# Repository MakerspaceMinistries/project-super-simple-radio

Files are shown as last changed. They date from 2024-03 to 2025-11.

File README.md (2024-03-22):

# Version Name #

`v<version>-<antenna type><audio output><station select><configuration location>`

- version: version number - corresponds with firmware
- antennta type: 
    O) onboard ESP32 antenna
    U) external antenna (following Espressif's convention)
- audio output:
    S) speakers
    L) line out
- station select:
    S) single station (no selector)
    M) multi station
- configuration location
    H) hardcoded
    R) remote

# Overview #

## Connecting to the radio for programming and debugging ##
There are two ways to connect: 

1. USB->Serial, using pads on the PCB
2. On board USB, via micro USB port on the PCB

USB->Serial appears to be the best for troubleshooting and development, as it is more verbose. To save money, this is achieved by connecting an extermal USB->Serial cable to pads on the PCB. This way one set of USB->Serial hardware can be used for multiple devices.

The ESP32 S3's onboard OTG USB does not appear to recieve the ESP32's debug messages, so it's not a solution for troubleshooting and development. However, it does provide a cheap way to make firmware updates more convenient.

### Linux ###

Create a udev rule so that it is not necessary to set permissions with each connection, by creating this file `/etc/udev/rules.d/99-esp32s3.rules` and adding this lines:

```
ATTRS{idVendor}=="303a", ATTRS{idProduct}=="1001", MODE="0666", ENV{ID_MM_DEVICE_IGNORE}="1", ENV{ID_MM_PORT_IGNORE}="1"
ATTRS{idVendor}=="0403", ATTRS{idProduct}=="6001", MODE="0666", ENV{ID_MM_DEVICE_IGNORE}="1", ENV{ID_MM_PORT_IGNORE}="1"
```

Then restart udev:

`sudo systemctl restart udev`

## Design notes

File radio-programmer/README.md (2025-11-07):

# Example Commands #

**Write Firmware**

python serial_programmer.py write_firmware -V v1.0.0-beta.6 -t /dev/ttyACM0

# Installing Firmware #

By default, the ESP32S3s cannot be programmed via the USB port. This needs to be enabled in firmware by writing the firmware over a serial connection.

## Compiling Firmware ##

You only need to do this if you've made changes to the source code. Otherwise, you can find the compiled firmware in this folder.

The README.md in the firmware folder explains how to compile new firmware.

# Workflow #

## Two Step (Prelim to Enable USB, Final over USB to update) ##

**If this is the first you are writing to the ESP32S3, then you MUST write to the serial interface. The USB can only be used to program *after* you have written firmware over the serial interface. The firmware will instruct the ESP32S3 to make the USB port available for writing firmware.**

1. Connect the board using an FTDI adapter (required if this is the first write) or via USB.
2. (Ignore this if writing over USB) Press the Reset->Program button.
3. Open a terminal and navigate to this folder and execute:
    Windows:
        .\write-firmware.bat v1.0.0-beta.2 [port ex: COM1] [folder of desired firmware version ex: v1.0.0]
    Linux:
        /./write-firmware.sh v1.0.0-beta.2 [port ex: /dev/ttyACM0] [folder of desired firmware version ex: v1.0.0]

TO HERE

<!-- 1. Writing the firmware.
    1. Using an adapter, write the firmware to the board before install in a box with esptool.py. This way it will be prepared to receive firmware and serial over the USB port
    2. Board is installed in box.
    3. (Optional) firmware is updated
    4. Python script generates an ID, sends it via serial, prints label to place on box. (Radio is added to database???) -->

## Misc ##

### Figuring out the command Arduino IDE uses to write firmware ###

To see how the Arduino IDE interacts with tools like esptool.py, you can change these settings to have the Arduino IDE output the commands used to Output window.

File -> Preferences -> Check the boxes for *Show diverse output during* compile & upload.

This can help to figure out how to write firmware using esptool.py, by providing a real world example.

You can also see which libraries are used, and where they are pulled from.

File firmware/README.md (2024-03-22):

# Compiling Firmware #

The ESP32S3 can be programmed through both the serial interface as well as the USB interface - if the USB interface has been enabled by first writing the proper firmware over the serial port. 

## 1. Board & Libraries ##

Install these versions of the board and libraries. Some of these may need to installed manually. 

  - Board: esp32 2.0.9
      IMPORTANT 2.0.13 Doesn't work. It causes an exception when connecting to a stream:
        Decoding stack results
        0x42013a7c:  is in WiFiClient::write(unsigned char const*, unsigned int) (/home/jake/.arduino15/packages/esp32/hardware/esp32/2.0.9/libraries/WiFi/src/WiFiClient.cpp:400).
        0x42013b85: WiFiClient::connected() at /home/jake/.arduino15/packages/esp32/hardware/esp32/2.0.9/libraries/WiFi/src/WiFiClient.cpp:535
        0x42022691: Audio::setDefaults() at /home/jake/Arduino/libraries/ESP32-audioI2S-3.0.0/src/Audio.cpp:137
        0x42022b12:  is in Audio::connecttohost(char const*, char const*, char const*) (/home/jake/Arduino/libraries/ESP32-audioI2S-3.0.0/src/Audio.cpp:412).
        0x4200578e:  is in Radio::Radio(RadioConfig*, WiFiManager*, Audio*) (/home/jake/repos/project-super-simple-radio/firmware/LEDStatus.h:132).
        0x4200a30c: Radio::loop() at /home/jake/repos/project-super-simple-radio/firmware/Radio.h:467
        0x4200a34a: Radio::loop() at /home/jake/repos/project-super-simple-radio/firmware/Radio.h:510
        0x4203c4c9: rmt_set_tx_thr_intr_en at /Users/ficeto/Desktop/ESP32/ESP32S2/esp-idf-public/components/hal/esp32s3/include/hal/rmt_ll.h:329

  - ESP32-audioI2S: 3.0.0 
      Examples/Docs/Source (Installed manually):
      - https://github.com/schreibfaul1/ESP32-audioI2S/blob/master/src/Audio.h
      - https://github.com/schreibfaul1/ESP32-audioI2S/blob/master/src/Audio.cpp
      - https://github.com/schreibfaul1/ESP32-audioI2S/blob/master/examples/Simple_WiFi_Radio/Simple_WiFi_Radio.ino

  - WiFiManager: 2.0.16-rc.2
    - https://github.com/tzapu/WiFiManager

ArduinoJSON: 6.21.2
  - https://arduinojson.org/?utm_source=meta&utm_medium=library.properties
  - 
## 2. Setting up Arduino's Tools ## 

1. Setup Tools menu with these options:
    - USB CDC on Boot: Enabled
    - USB DFU on Boot: Disabled
    - USB Firmware MSC on Boot: Disabled
    - PSRAM: OPI PSRAM
    - Upload Mode UART
    - USB Mode: Hardware CDC and JTAG

2. Select the ESP32S3 Dev Module as the board (Select the port as well, if you are writing to a device)

## 3. Compiling ##

You can compile and either write directly to a radio, or generate a firmware file.

### 3a. Compiling & Writing to Device ###

If this is the first time you are writing firmware, you will need to use an FTDI adapter to write over serial. Once that has been done, you will be able to write using the USB port.

1. (If writing over USB, you can skip this) Press the program reset button on the board to boot to programming mode.
2. Click the upload button or ctrl+u. 

### 3b. Compiling to a File ###

1. Go to Sketch->Export Compiled Binary

This will create a set of files in the same folder as the firmware, inside a folder/subfolder:

./build/esp32.esp32.esp32s3/

There you will find a few files.

# Helpful Docs #

Using the on board USB for programming is documented here:
  - https://docs.espressif.com/projects/arduino-esp32/en/latest/api/usb_cdc.html
  - https://docs.espressif.com/projects/arduino-esp32/en/latest/tutorials/cdc_dfu_flash.html#usb-cdc

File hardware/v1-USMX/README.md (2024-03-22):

# Parts & Datasheets #

## ESP32-S3-WROOM-1U-N16R8 ##

Purchase: https://www.mouser.com/ProductDetail/356-ESP32S3WM1UN16R8

### Datasheets And Other Resources ###

Many of the circuits required for the radio are also found on the ESP32 S3 Dev Kits & ESP32 S3 Korvo Dev Board, . The schematics are helpful for reference.

- Espressif datasheet for the ESP32-S3-WROOM-1/U module https://www.espressif.com/sites/default/files/documentation/esp32-s3-wroom-1_wroom-1u_datasheet_en.pdf
    - Page 25: example schematics
    - Page 12: strapping pins
    - Page 10-11: module pinout
- Espressif ESP32 hardware design guidelines https://www.espressif.com/sites/default/files/documentation/esp32_hardware_design_guidelines_en.pdf
- ESP32 S3 Dev Kit Schematics https://dl.espressif.com/dl/schematics/SCH_ESP32-S3-DevKitC-1_V1.1_20220413.pdf
- ESP32 S3 Dev Kit PCB Layout: https://dl.espressif.com/dl/schematics/PCB_ESP32-S3-DevKitC-1_V1.1_20220429.pdf
- Other Dev Kit resources: https://docs.espressif.com/projects/esp-idf/en/latest/esp32s3/hw-reference/esp32s3/user-guide-devkitc-1.html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
- ESP32 S3 Korvo (an audio dev board from Espressif): https://docs.espressif.com/projects/esp-adf/en/latest/design-guide/dev-boards/user-guide-esp32-s3-korvo-2.html

### Footprints/Schematics ###

Download or clone the Espressif Library repo: https://github.com/espressif/kicad-libraries

Install the symbols, footprints, and 3D models:

1. `Preferences` -> `Manage Symbol Libraries` and add a library and specify the `libraries/Espressif.kicad_sym` in the repo as the Library Path.
2. `Preferences` -> `Manage Footprint Libraries` and add a library and specify the `footprints\Espressif.pretty` in the repo as the Library Path.
3. `Preferences` -> `Configure Paths`
    * Create a new variable:
        * Name: `ESPRESSIF_3DMODELS`
        * Path: `<path to the folder kicad-libraries/3d>`

## MAX98357AETE+T - DAC & Amplifier ##

Datasheet: https://www.mouser.com/datasheet/2/256/MAX98357A-MAX98357B-271244.pdf  
Purchase: https://www.mouser.com/ProductDetail/Maxim-Integrated/MAX98357AETE%2bT?qs=AAveGqk956HhNpoJjF5x2g%3D%3D
Footprint/Schematic: https://componentsearchengine.com/part-view/MAX98357AETE%2BT/Maxim%20Integrated 

## AZ1084CD-3.3TRG1 - Voltage Regulator (3.3v) ##

Datasheet: https://www.diodes.com/assets/Datasheets/AZ1084C.pdf  
Purchase: https://www.mouser.com/ProductDetail/621-AZ1084CD-3.3TRG1

This footprint and schematic are for the same line as the AZ1084CD-3.3TRG1

https://componentsearchengine.com/part-view/AZ1084CD-ADJTRG1/Diodes%20Inc.

## P110KH1-0F15BR10Kb - Volume Potentiomoter ##

Datasheet: https://www.mouser.com/datasheet/2/414/TTRB_S_A0010315417_1-2565498.pdf  
Purchase: https://www.mouser.com/ProductDetail/BI-Technologies-TT-Electronics/P110KH1-0F15BR10K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
Footprint/Schematic: https://componentsearchengine.com/part-view/P110KH1-0F15BR10K/BI%20Technologies

## PTA3043-2015DPB104 - Station Potentiometer ##

Datasheet: https://www.mouser.com/datasheet/2/54/pta-778345.pdf  
Purchase:  https://www.mouser.com/ProductDetail/Bourns/PTA3043-2015DPB104?qs=zRGnDeWDVj0fVt3rAxibYA%3D%3D
Footprint/Schematic: https://componentsearchengine.com/part-view/PTA3043-2015DPB104/Bourns

## CLMVC-FKC-CGJJM569aBB7a343 - RGB LED ##

Datasheet: https://www.mouser.com/datasheet/2/723/1273_CLMVC_FKA-2326704.pdf  
Purchase: https://www.mouser.com/ProductDetail/Cree-LED/CLMVC-FKC-CGJJM569aBB7a343?qs=1mbolxNpo8epafm4p5CBBQ%3D%3D

The footprint and schematic for the CLMVC-FKC-CGJJM569aBB7a343 wasn't available, however, this LED has the same packing and pinout.

https://componentsearchengine.com/part-view/CLMVC-FKA-CL1D1L71BB7C3C3/Wolfspeed

## GG060305100N2P - ESD Suppressor ##

***IMPORTANT*** & ***TODO***  
*The selection of this ESD suppressor may be wrong. The ESP32 S3 Dev Kit and the ESP32 S3 Korvo both use the LESD5D5.0CT1G, which is no longer available. The GG060305100N2P appears to have similar specs, but this should be verified by someone with who is more knowledgeable*

Datasheet: https://www.mouser.com/datasheet/2/40/AVX_GiGuard-2401264.pdf  
Purchase: https://www.mouser.com/ProductDetail/KYOCERA-AVX/GG060305100N2P?qs=QNEnbhJQKvZ38qL0Ea5hYg%3D%3D  
Package/Case: 0603 (1610 metric)
Footprint/Schematic: https://componentsearchengine.com/part-view/GG060305100N2P/Kyocera%20AVX

## Resistors ##

Package/case: 1206/3216 (in/mm)
Footprint: Built-in 1206 footprint

270 ohm
- CR1206-FX-2700ELF
- https://www.mouser.com/ProductDetail/Bourns/CR1206-FX-2700ELF?qs=UUWDWenVDLhTOwaXSP1D9Q%3D%3D

10k ohm
- CR1206-FX-1002ELF
- https://www.mouser.com/ProductDetail/Bourns/CR1206-FX-1002ELF?qs=3wWX5hyYeeQyTehaX7pP%252BA%3D%3D

220k ohm
- CR1206-FX-2203ELF
- https://www.mouser.com/ProductDetail/Bourns/CR1206-FX-2203ELF?qs=UUWDWenVDLhp0KvMMxHtXw%3D%3D

## 10uF Ceramic Capacitor ##

Package/case: 0805/2012 (in/mm)
Footprint: Built-in 0805 footprint

10uF 16v
- Model: CL21B106KAYQNNE
- Purchase: https://www.mouser.com/ProductDetail/187-CL21A106KOQNNNG

0.1uF 25v
- Model: CL21B104KACNNNC
- Purchase: https://www.mouser.com/ProductDetail/Samsung-Electro-Mechanics/CL21B104KACNNNC?qs=yOVawPpwOwnhB47kNbieFw%3D%3D

## Tactile Switches - Reset and Reset & Program ##

Datasheet: https://www.mouser.com/datasheet/2/240/pts526-3050698.pdf 
Purchase: https://www.mouser.com/ProductDetail/CK/PTS526-SM08-SMTR2-LFS?qs=UXgszm6BlbFgRZzlfGAMFg%3D%3D
Footprint/Shematic: https://componentsearchengine.com/part-view/PTS526%20SM08%20SMTR2%20LFS/C%20%26%20K%20COMPONENTS

## USB Micro ##

Datasheet: https://cdn.amphenol-cs.com/media/wysiwyg/files/documentation/datasheet/inputoutput/io_usb_micro.pdf
Drawing: https://www.amphenol-cs.com/media/wysiwyg/files/drawing/10118192.pdf  
Purchase: https://www.mouser.com/ProductDetail/Amphenol-FCI/10118192-0002LF?qs=KVgMXE4aH4nIkuWlMxQzog%3D%3D
Footprint/Schematic: https://componentsearchengine.com/part-view/10118192-0002LF/Amphenol%20Communication%20Solutions 

# Other Hardware Options #

These are options that were not used, but may be useful for future designs.

## Speakers ##
https://www.aliexpress.us/item/2251832407677186.html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

## 90 Tactile Switch - Reset ##
https://www.mouser.com/ProductDetail/E-Switch/TL3336AF160Q?qs=iLbezkQI%252Bshf0NMs3%252BGhxA%3D%3D

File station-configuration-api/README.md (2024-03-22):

# Database #
----

TODO: initialize the database with a default admin/password.

# API Endpoints #
----

This documentation follows this template: https://gist.github.com/iros/3426278

** /admins **
** /admins/sessions **
** /networks **
** /networks/stations **
** /networks/<int:network_id>/stations/<int:station_id> **
** /radios **
** /radios/<radio_id> **
** /radios/<radio_id>/device_interface/v1.0 **

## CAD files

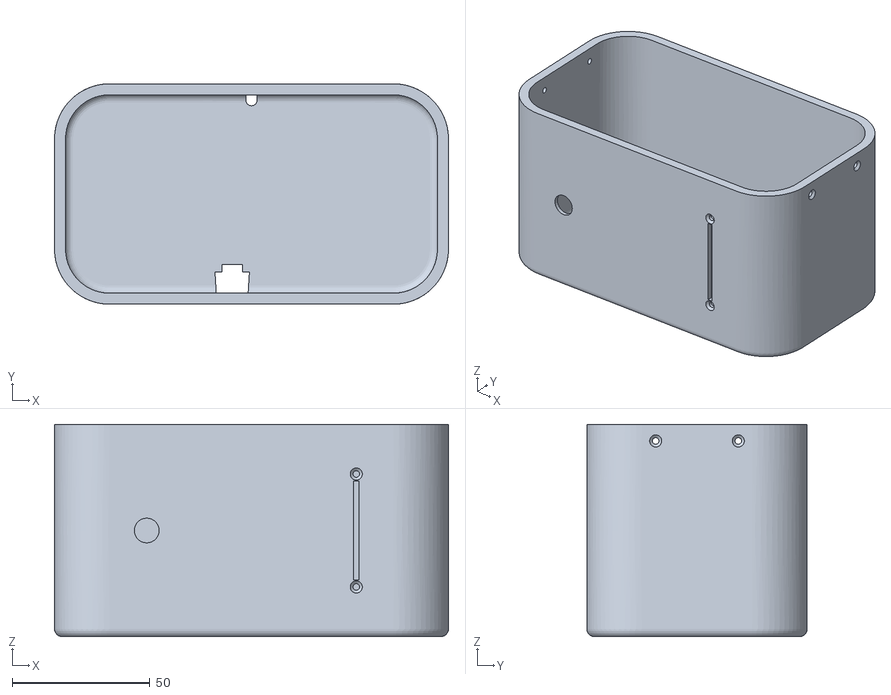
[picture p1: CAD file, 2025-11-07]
hardware/Housing/Housing.stl
143.0 x 80.0 x 77.0

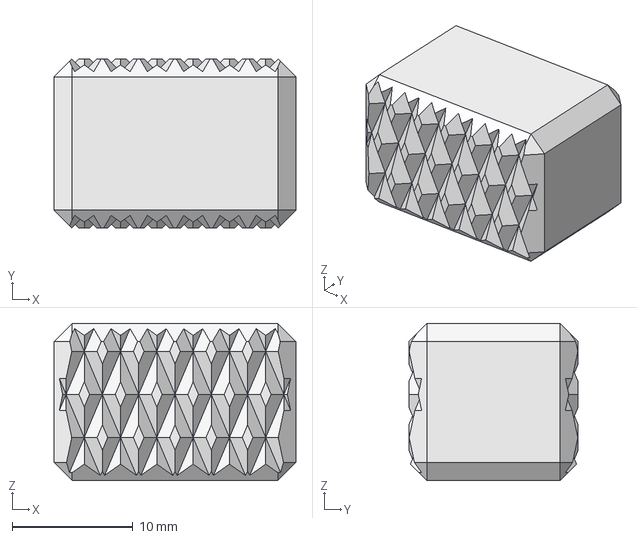
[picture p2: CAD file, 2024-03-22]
hardware/Knobs/volume-knobs/channel-knob.FCStd
20.0 x 14.0 x 13.0 mm

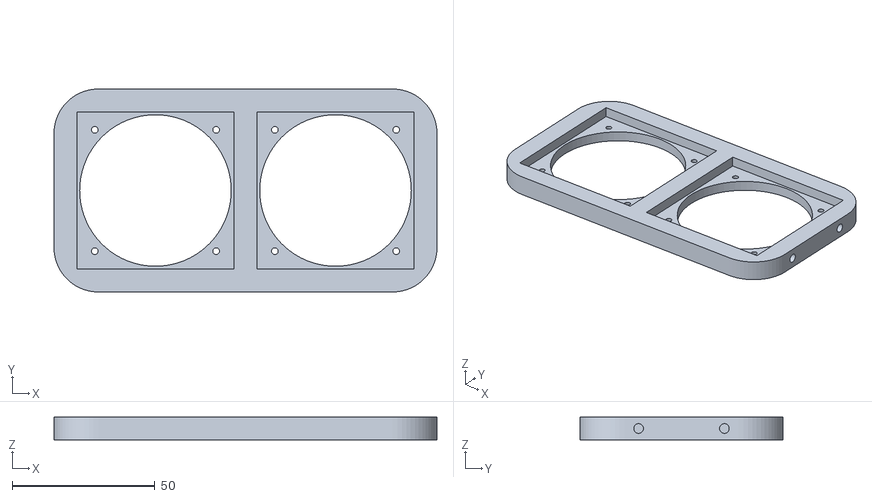
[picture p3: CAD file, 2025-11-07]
hardware/Housing/Speakers.stl
134.0 x 71.0 x 8.00

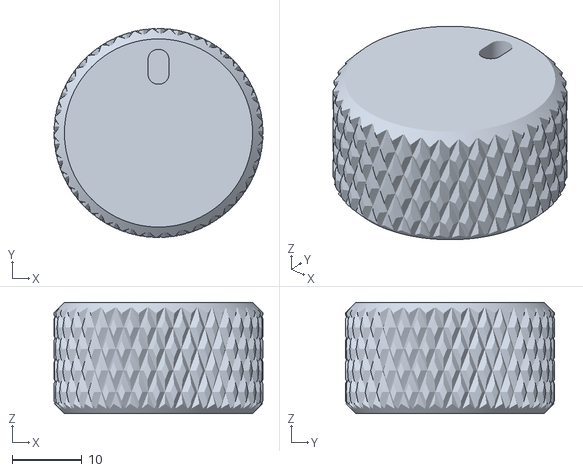
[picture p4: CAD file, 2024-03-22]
hardware/Knobs/volume-knobs/v1.stl
30.0 x 30.0 x 16.0

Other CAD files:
hardware/Knobs/volume-knobs/channel-v1.stl

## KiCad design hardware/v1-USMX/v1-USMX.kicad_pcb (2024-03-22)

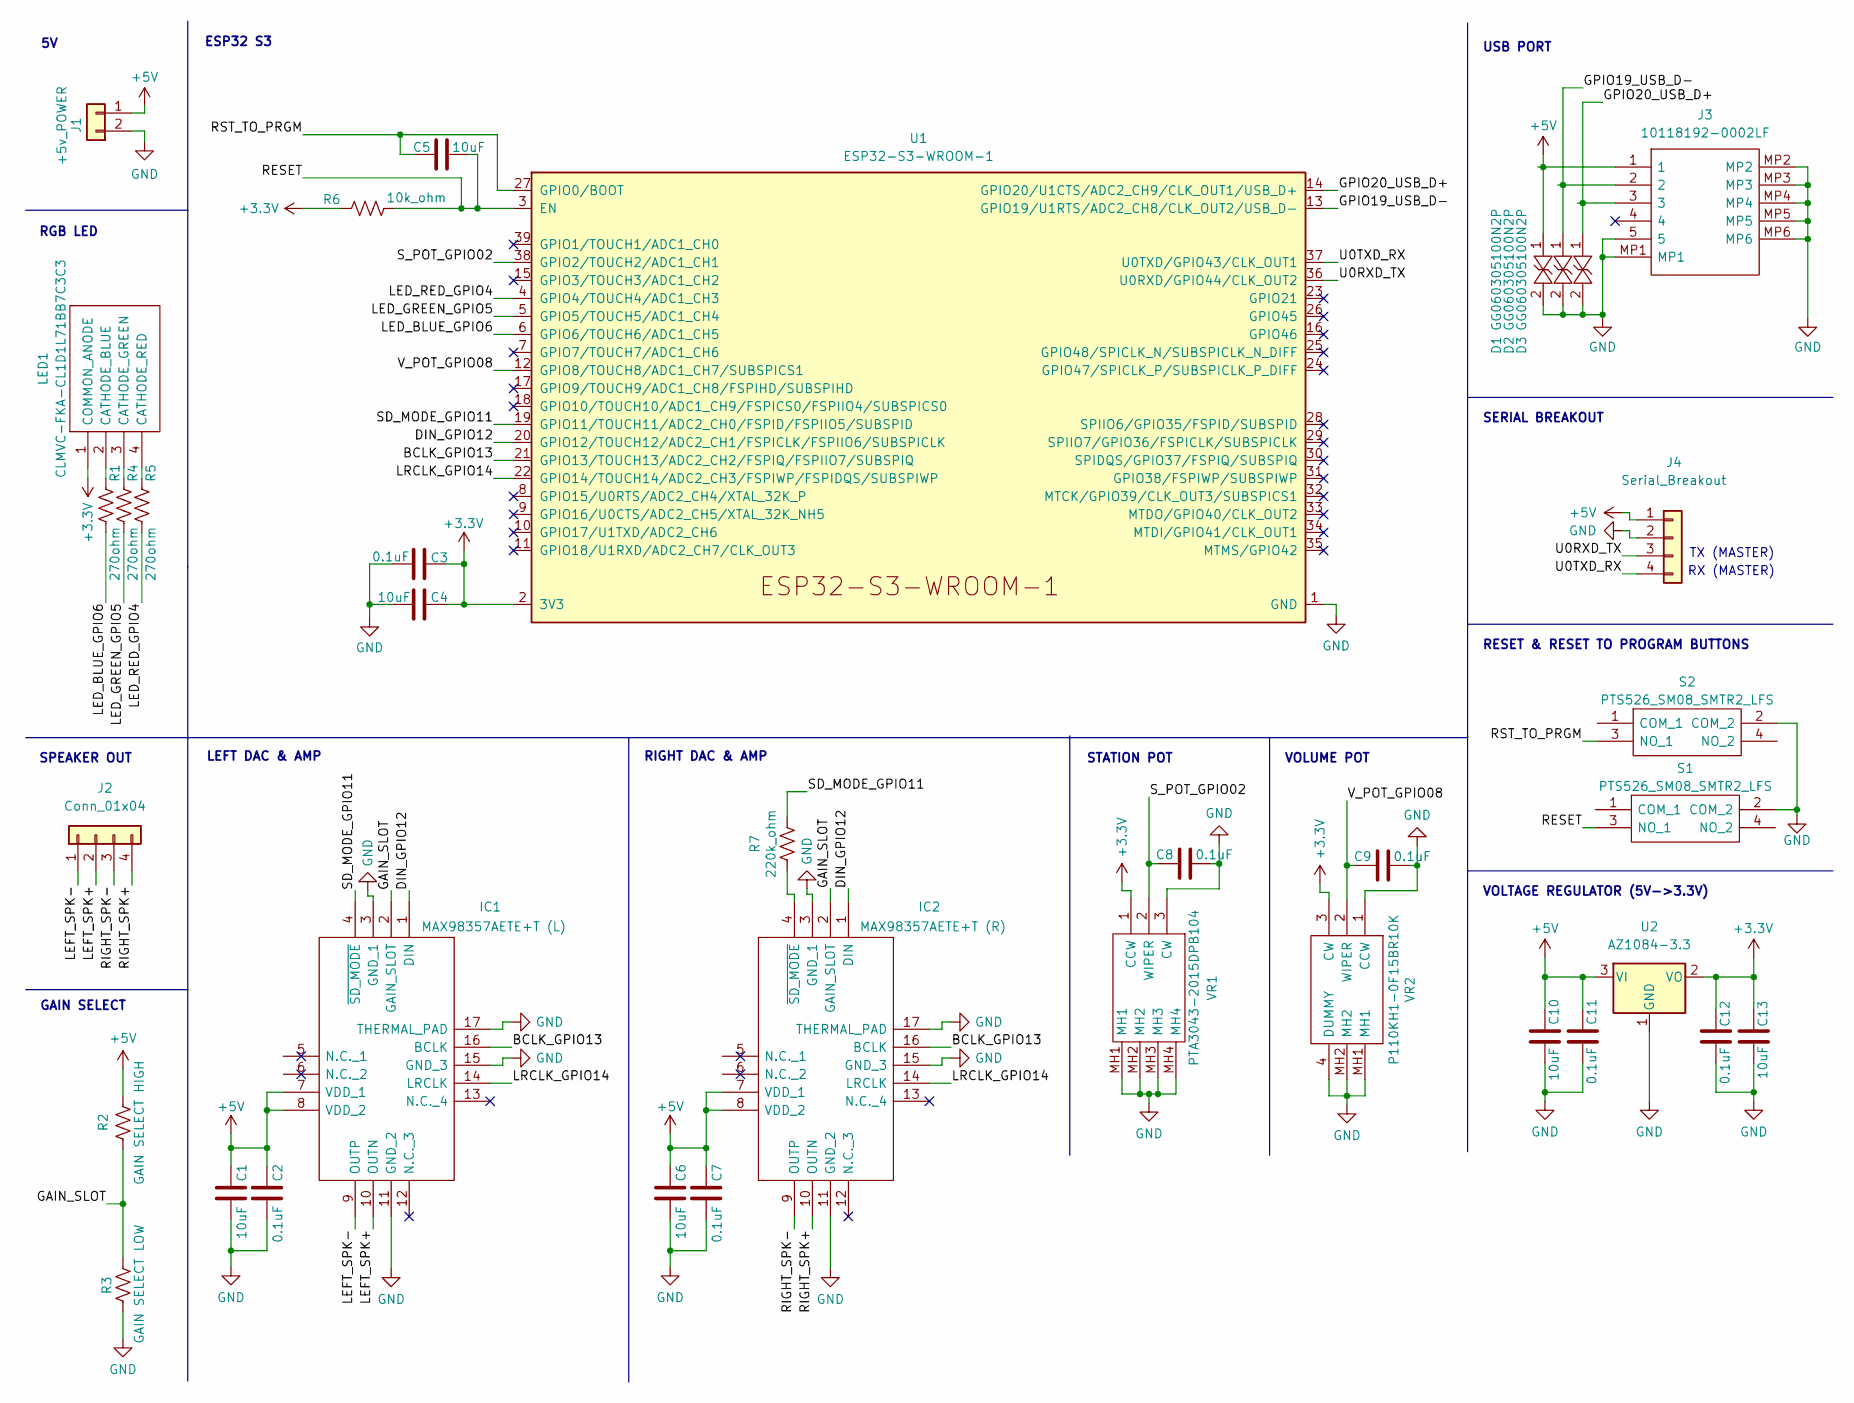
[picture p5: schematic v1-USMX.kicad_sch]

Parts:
C1, C4, C5, C6, C10, C13: 10uF; C_0805_2012Metric
C2, C3, C7, C8, C9, C11, C12: 0.1uF; C_0805_2012Metric
D1, D2, D3: GG060305100N2P; DIONC1608X70N; Manufacturer_Part_Number GG060305100N2P; Mouser Part Number 581-GG060305100N2P
IC1: MAX98357AETE+T (L); QFN50P300X300X80-17N; Manufacturer_Part_Number MAX98357AETE+T; Mouser Part Number 700-MAX98357AETE+T
IC2: MAX98357AETE+T (R); QFN50P300X300X80-17N; Manufacturer_Part_Number MAX98357AETE+T; Mouser Part Number 700-MAX98357AETE+T
J1: +5v_POWER; CUSTOM_5V_SOLDER_PADS
J2: Conn_01x04; JST_XH_B4B-XH-A_1x04_P2.50mm_Vertical
J3: 10118192-0002LF; 101181920002LF; Manufacturer_Part_Number 10118192-0002LF; Mouser Part Number 649-10118192-0002LF
J4: Serial_Breakout; PinHeader_2x02_P2.54mm_Vertical
LED1: CLMVC-FKA-CL1D1L71BB7C3C3; CLMVCFKACL1D1L71BB7C3C3; Manufacturer_Part_Number CLMVC-FKA-CL1D1L71BB7C3C3; Mouser Part Number 941-CLMVCFKACL1D1L71
R1, R4, R5: 270ohm; R_1206_3216Metric
R2: GAIN SELECT HIGH; R_1206_3216Metric
R3: GAIN SELECT LOW; R_1206_3216Metric
R6: 10k_ohm; R_1206_3216Metric
R7: 220k_ohm; R_1206_3216Metric
S1, S2: PTS526_SM08_SMTR2_LFS; PTS526SM08SMTR2LFS; Manufacturer_Part_Number PTS526 SM08 SMTR2 LFS; Mouser Part Number 611-PTS526SM08SMTR2L
U1: ESP32-S3-WROOM-1; ESP32-S3-WROOM-1U
U2: AZ1084-3.3; TO-252-2
VR1: PTA3043-2015DPB104; PTA30432015DPB104; Manufacturer_Part_Number PTA3043-2015DPB104; Mouser Part Number 652-PTA30432015B104
VR2: P110KH1-0F15BR10K; P110KH10F15BR10K; Manufacturer_Part_Number P110KH1-0F15BR10K; Mouser Part Number 858-P110KH10F15BR10K

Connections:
+3.3V: C3.1, C4.1, C12.1, C13.1, LED1.1 (COMMON_ANODE), R6.1, U1.2 (3V3), U2.2 (VO), VR1.1 (CCW), VR2.3 (CW)
+5V: C1.1, C2.1, C6.1, C7.1, C10.1, C11.1, D1.1, IC1.7 (VDD_1), IC1.8 (VDD_2), IC2.7 (VDD_1), IC2.8 (VDD_2), J1.1, J3.1, J4.1, R2.1, U2.3 (VI)
/BCLK_GPIO13: IC1.16 (BCLK), IC2.16 (BCLK), U1.21 (GPIO13/TOUCH13/ADC2_CH2/FSPIQ/FSPIIO7/S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)
/DIN_GPIO12: IC1.1 (DIN), IC2.1 (DIN), U1.20 (GPIO12/TOUCH12/ADC2_CH1/FSPICLK/FSPIIO6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)
/GAIN_SLOT: IC1.2 (GAIN_SLOT), IC2.2 (GAIN_SLOT), R2.2, R3.2
/GPIO19_USB_D-: D2.1, J3.2, U1.13 (GPIO19/U1RTS/ADC2_CH8/CLK_OUT2/USB_D-)
/GPIO20_USB_D+: D3.1, J3.3, U1.14 (GPIO20/U1CTS/ADC2_CH9/CLK_OUT1/USB_D+)
/LED_BLUE_GPIO6: R1.1, U1.6 (GPIO6/TOUCH6/ADC1_CH5)
/LED_GREEN_GPIO5: R4.1, U1.5 (GPIO5/TOUCH5/ADC1_CH4)
/LED_RED_GPIO4: R5.1, U1.4 (GPIO4/TOUCH4/ADC1_CH3)
/LEFT_SPK+: IC1.10 (OUTN), J2.2
/LEFT_SPK-: IC1.9 (OUTP), J2.1
/LRCLK_GPIO14: IC1.14 (LRCLK), IC2.14 (LRCLK), U1.22 (GPIO14/TOUCH14/ADC2_CH3/FSPIWP/FSPIDQS/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)
/RESET: C5.1, R6.2, S1.3 (NO_1), U1.3 (EN)
/RIGHT_SPK+: IC2.10 (OUTN), J2.4
/RIGHT_SPK-: IC2.9 (OUTP), J2.3
/RST_TO_PRGM: C5.2, S2.3 (NO_1), U1.27 (GPIO0/BOOT)
/SD_MODE_GPIO11: IC1.4 (~SD_MODE), R7.2, U1.19 (GPIO11/TOUCH11/ADC2_CH0/FSPID/FSPIIO5/S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)
/S_POT_GPIO02: C8.1, U1.38 (GPIO2/TOUCH2/ADC1_CH1), VR1.2 (WIPER)
/U0RXD_TX: J4.3, U1.36 (U0RXD/GPIO44/CLK_OUT2)
/U0TXD_RX: J4.4, U1.37 (U0TXD/GPIO43/CLK_OUT1)
/V_POT_GPIO08: C9.1, U1.12 (GPIO8/TOUCH8/ADC1_CH7/SUBSPICS1), VR2.2 (WIPER)
GND: C1.2, C2.2, C3.2, C4.2, C6.2, C7.2, C8.2, C9.2, C10.2, C11.2, C12.2, C13.2, D1.2, D2.2, D3.2, IC1.3 (GND_1), IC1.11 (GND_2), IC1.15 (GND_3), IC1.17 (THERMAL_PAD), IC2.3 (GND_1), IC2.11 (GND_2), IC2.15 (GND_3), IC2.17 (THERMAL_PAD), J1.2, J3.5, J3.MP1, J3.MP2, J3.MP3, J3.MP4, J3.MP5, J3.MP6, J4.2, R3.1, S1.2 (COM_2), S2.2 (COM_2), U1.1 (GND), U1.40 (GND), U1.41 (GND), U2.1 (GND), VR1.3 (CW), VR1.MH1, VR1.MH2, VR1.MH3, VR1.MH4, VR2.1 (CCW), VR2.4 (DUMMY), VR2.MH1, VR2.MH2
unnamed: IC2.4 (~SD_MODE), R7.1
unnamed: LED1.2 (CATHODE_BLUE), R1.2
unnamed: LED1.3 (CATHODE_GREEN), R4.2
unnamed: LED1.4 (CATHODE_RED), R5.2

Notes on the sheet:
RESET & RESET TO PROGRAM BUTTONS
RGB LED
VOLUME POT
LEFT DAC & AMP
STATION POT
SPEAKER OUT
RIGHT DAC & AMP
ESP32 S3
SERIAL BREAKOUT
USB PORT
GAIN SELECT
VOLTAGE REGULATOR (5V->3.3V)
RX (MASTER)
TX (MASTER)

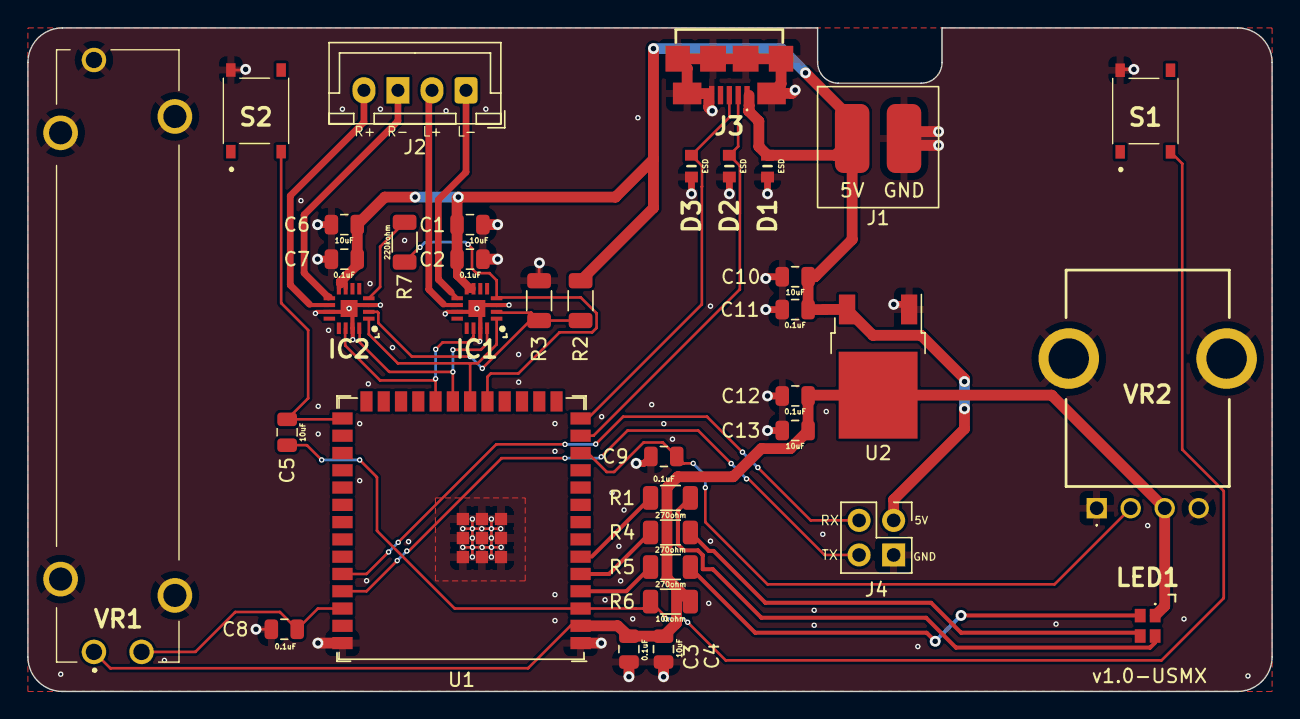
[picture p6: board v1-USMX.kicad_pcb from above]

Board: 2 copper layers, 91.4 x 48.8 mm, 36 parts (0 on the bottom side), 27 nets.

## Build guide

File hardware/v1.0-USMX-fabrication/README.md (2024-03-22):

The fabrication files were created following this guide:

https://jlcpcb.com/help/article/362-how-to-generate-gerber-and-drill-files-in-kicad-7

All of the generated files were put in a zip file, which was uploaded the JLCPCB order page.

Aside from the quantity, all of the defaults were used.

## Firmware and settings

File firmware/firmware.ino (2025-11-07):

/*

Example serial messages for configuring the radio. It is too large to send all at once, so it is broken into parts.

{
  "remote_cfg_url":"http://config.example.com/api/v1/radios/device_interface/v1.0/",
  "radio_id":"test-radio",
  "pcb_version":"v1-USMX.beta-1",
  "remote_config":true,
  "has_channel_pot":true,
  "station_count":4
}

{ 
  "remote_config_background_retrieval_interval": 43200000 
}

{
  "stn_1_url":"http://example.com/connect-test.mp3",
  "stn_2_url":"http://example.com/connect-test.mp3"
}

{
  "stn_3_url":"http://example.com/connect-test.mp3",
  "stn_4_url":"http://example.com/connect-test.mp3"
}

Example message for resetting the stored preferences and restarting the ESP.

{"clear_preferences": true}
{"restart_esp": true}

TODO document: reset_wifi, debug_mode, ssid, pass

States: 
  - Green               LED_STATUS_SUCCESS              success
  - Green (blinking)    LED_STATUS_SUCCESS_BLINKING     success (blinking)
  - Blue                LED_STATUS_INFO                 info
  - Blue (blinking)     LED_STATUS_INFO_BLINKING        info (blinking)
  - Yellow              LED_STATUS_WARNING              warning
  - Yellow              LED_STATUS_WARNING_BLINKING     warning (blinking)
  - Red                 LED_STATUS_ERROR                error
  - Red (blinking)      LED_STATUS_ERROR_BLINKING       error (blinking)

*/
#define FIRMWARE_VERSION "v1.0.0-beta.6"

#include <WiFiManager.h>
#include "Audio.h"
#include "Radio.h"

RadioConfig radio_config;
WiFiManager wifi_manager;
Audio audio;
LEDStatusConfig led_status_config;

Radio radio(&radio_config, &wifi_manager, &audio, &led_status_config);

// Callbacks which need the radio instance
void audio_info(const char *info) {
  // Triggered once a feed is played.
  if (radio.m_debug_mode) {
    Serial.print("info:");
    Serial.println(info);
  }
}

void wifi_manager_setup_callback(WiFiManager *myWiFiManager) {
  radio.m_led_status.set_status(RADIO_STATUS_450_UNABLE_TO_CONNECT_TO_WIFI_WM_ACTIVE);
  if (radio.m_debug_mode) {
    Serial.println("Entered config mode");
    Serial.println(WiFi.softAPIP());
    Serial.print("Created config portal AP ");
    Serial.println(myWiFiManager->getConfigPortalSSID());
  }
}

void setup() {

  // radio.m_debug_mode = true;

  wifi_manager.setAPCallback(wifi_manager_setup_callback);
  radio.init();
}

void loop() {
  radio.loop();
}

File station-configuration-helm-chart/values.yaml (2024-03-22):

api:
  name: ssr-config-api
  replicas: 1
  path: /api/
  image: jaketeater/super-simple-radio-station-config-api
  imageTag: latest
  containerPort: 80
  servicePort: 80
  ingressPort: 80
  host: config.acc-radio.raiotech.com

client:
  name: ssr-client
  replicas: 1
  path: /
  image: jaketeater/super-simple-radio-configuration-client
  imageTag: latest
  containerPort: 80
  servicePort: 80
  ingressPort: 80
  host: config.acc-radio.raiotech.com

# <add to a secrets.yaml file>
# api:
#   FLASK_SECRET_KEY: <insert your value>
#   WEBSITE_DB_HOST: <insert your value>
#   WEBSITE_DB_USER: <insert your value>
#   WEBSITE_DB_PASS: <insert your value>
#   WEBSITE_DB_DATABASE: <insert your value>
#   PASSWORD_SALT: <insert your value>

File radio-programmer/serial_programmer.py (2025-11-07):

# This needs refactored and a class object should probably be used.


# Examples:

# Auto detect the serial port and write firmware.
# python serial_programmer.py write_firmware -d --firmware-version v1.0.0-beta.2

# Auto detect the serial port and create from a config file.
# python serial_programmer.py create -d --file settings.json


import serial
import json
import argparse
import requests
from time import sleep
from qr_code_webcam import detect_and_decode_qr
import esptool
from libs.detect_serial_ports import serial_ports

parser = argparse.ArgumentParser(description='Command line radio configuration.')

parser.add_argument('action', help='Action to be performed.', choices=['create', 'update', 'write_firmware'])

parser.add_argument('-a', '--api-version',  default='v1', type=str, help='Version of the api to use. Default: v1') 
parser.add_argument('-b', '--pcb-version', type=str, help='PCB version.')
parser.add_argument('-c', '--config-endpoint-version', type=str, default='v1.0', help='v1.0')
parser.add_argument('-d', '--auto-detect-serial-port', action='store_true', default=False, help='Attempt to detect a serial port and write to it. UNPLUG OTHER SERIAL DEVICES.')
parser.add_argument('-e', '--has-channel-pot', default=True, type=bool, help='has_channel_pot')
parser.add_argument('-f', '--file', help='Path to the settings file')
parser.add_argument('-H', '--host', type=str, help='Host of the radio configuration server.') 
# parser.add_argument('-i', '--radio-id', type=str, help='ID of the radio. If blank, it will use the webcam to scan for a QR code that contains a URL that ends in a UUID and it will create a radio in the database.')
parser.add_argument('-l', '--label', type=str, help='Label for the radio.')
parser.add_argument('-n', '--network', type=int, help='network_id of the network to which the radio belongs.')
parser.add_argument('-p', '--password', type=str, help='Password for the configuration server.')
parser.add_argument('-r', '--remote-config-background-retrieval-interval', default=43200000, type=int, help='remote_config_background_retrieval_interval')
parser.add_argument('-s', '--default-station', default=None, type=str, help='Default station to be written into position 0.')
parser.add_argument('-t', '--target', default=None, type=str, help='Target device to write to. Default: /dev/ttyACM0')
parser.add_argument('-u', '--user', type=str, help='User name for the configuration server.')
parser.add_argument('-V', '--firmware-version', type=str, help='Version used when writing firmware. Ex: v1.0.0')
parser.add_argument('-w', '--wifi', action='store_true', help='Configure the radio to connect to the default WiFi Network.')

args = parser.parse_args()

def read_config(ser):
    ser.flush()
    ser.write("{}".encode())
    while True:
        ser.write("{}".encode())
        sleep(0.25)
        print('.', end='', flush=True)
        data = ser.read_all().decode().strip()
        if data:
            print(data, flush=True)
            break

def create_radio(args, radio_id):
    with requests.Session() as session:

        # Construct login URL
        login_url = f"{args.host}/api/{args.api_version}/admins/sessions"
        
        # Login payload
        login_payload = {
            'username': args.user,
            'password': args.password
        }

        # Attempt to log in
        response = session.post(login_url, json=login_payload)

        if response.status_code < 400:
            
            # Construct create radio URL
            create_radio_url = f"{args.host}/api/{args.api_version}/radios"
            
            # Create radio payload
            radio_payload = {
                'radio_id': radio_id,
                'network_id': args.network,
                'label': args.label
            }
            
            # Attempt to create the radio
            create_response = session.post(create_radio_url, json=radio_payload)

            if create_response.status_code > 399:
                error_message = create_response.json()["message"]
                raise Exception(f"Failed to create radio: {error_message}")
            
            return radio_id
        
        else:
            raise Exception("Failed to log in")

def write_to_serial(ser, payload):
    # Check if the payload is a dictionary
    if isinstance(payload, dict):
        # Convert the dictionary to a JSON string
        payload = json.dumps(payload)
    
    # Write the payload to the serial port
    # The encode() method converts the string to bytes, which is required by the write() method
    print(f"Writing: {payload}")
    ser.write(payload.encode())
    sleep(0.2)


def update_radio(ser, args, radio_id):
    read_config(ser)
    write_key_value_to_serial(ser, "remote_config",  True)
    write_key_value_to_serial(ser, "radio_id", radio_id)
    write_key_value_to_serial(ser, "remote_cfg_url",  f"{args.host}/api/{args.api_version}/radios/device_interface/{args.config_endpoint_version}/")
    write_key_value_to_serial(ser, "has_channel_pot",  args.has_channel_pot)
    write_key_value_to_serial(ser, "pcb_version", args.pcb_version )
    write_key_value_to_serial(ser, "remote_config_background_retrieval_interval", args.remote_config_background_retrieval_interval )
    if args.default_station:
        write_key_value_to_serial(ser, "stn_1_url", args.default_station)
    read_config(ser)

    # This will restart the ESP, so run last.
    if args.wifi:
        wifi_creds = {"ssid": "radio-setup", "pass": "supersimpleradio"}
        write_to_serial(ser, wifi_creds)

def write_key_value_to_serial(ser, key, value):
    kv = {key:value}
    write_to_serial(ser, kv)
    while True:
        sleep(0.1)
        data = ser.read_all().decode().strip()
        if data:
            break
    sleep(0.1)

def load_settings_file(args):
    with open(args.file, 'r') as file:
        settings = json.load(file)
        for key in settings:
            args.__setattr__(key, settings[key])
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

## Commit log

2022-11-13 init dir structure
    [hardware.kicad_pcb, hardware.kicad_sch]
2022-11-13 init work on hardware
    [v1-PSMX.kicad_pcb, v1-PSMX.kicad_sch]
2022-11-25 Init work on a schematic
    [v1-PSMX.kicad_pcb, v1-PSMX.kicad_sch]
2022-11-26 Init work on hardware schematic
    [v1-PSMX.kicad_sch]
2022-11-28 Init work on schematic
    [v1-PSMX.kicad_sch]
2022-11-28 Improvements to schematic
    [v1-PSMX.kicad_sch]
2022-11-29 Added ESD protection to USB connection
    [v1-PSMX.kicad_sch]
2022-12-06 Completed Init work on schematic
    [v1-PSMX.kicad_pcb, v1-PSMX.kicad_sch]
2022-12-11 init work on pcb
    [v1-PSMX.kicad_pcb, v1-PSMX.kicad_sch]
2022-12-14 all routed, but needs organized
    [v1-PSMX.kicad_pcb, v1-PSMX.kicad_sch]
2022-12-14 Cleaned up pcb
    [v1-PSMX.kicad_pcb, v1-PSMX.kicad_sch]
2022-12-15 added silk screen labels for resistor and diode size
    [v1-PSMX.kicad_pcb]
2022-12-15 added version number
    [v1-PSMX.kicad_pcb]
2022-12-15 Added some more labels
    [v1-PSMX.kicad_pcb]
2022-12-16 Updated track widths to work with 1oz
    [v1-PSMX.kicad_pcb]
2022-12-16 added screw hole, misc improvements
    [v1-PSMX.kicad_pcb]
2023-01-08 passes all DRC
    [v1-USMX.kicad_pcb]
2023-01-08 Created Gerbers And Drill
    [v1-USMX-B_Cu.gbl, v1-USMX-B_Mask.gbs, v1-USMX-B_Paste.gbp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]
2023-01-17 Added LED statuses, including a blinking - giving 8 possible states.
2023-01-21 Moved LED Status into its own object & added items to the todo list.
2023-01-21 PCB is passing tests, locked footprints and outline in place.
    [v1-USMX.kicad_pcb]
2023-01-21 Increased the size of some silk screen
    [v1-USMX.kicad_pcb]
2023-01-21 Added ground plane to top, vias at extremeties
    [v1-USMX.kicad_pcb]
2023-01-21 Added LED status to be used during startup. Added wifi connection check
2023-01-21 Added object to read the current channel index from the channel pot
2023-02-15 Added a helm chart for the api server, fixed bug where column that didn't exist was selected
    [values.yaml]
2023-02-17 refactored the device interface to a GET, moved the radioID to the end of the URL, to make it easier to work with, moved from array of stations to key/value
2023-07-08 Fixed bug in stream loss detection
    [Radio.h]
2023-07-13 Major refactor to add status codes to drive the LEDs, and general refactoring
2023-07-13 Fixed bug where LED Statuses were cleared in the wrong direction, improved name
    [LEDStatus.h, Radio.h]
2023-09-25 The streamIsAdvancing() is not working and now just returns true
    [Radio.h]
2023-09-26 Broke up example of serial config into two parts since it won't send otherwise
    [firmware.ino]
2023-09-26 Reworked how some strings are sent to serial
    [Radio.h]
2023-09-26 Fixed the LED status for when it can't connect to wifi so that it blinks
    [Radio.h, firmware.ino]
2023-09-27 Fixed bug where the UNABLE_TO_CONNECT_TO_WIFI_WM_ACTIVE status wasn't cleared after a good connection
    [Radio.h]
2023-09-27 The response from wifiManager->autoConnect("Radio Setup"); is never false (in a practical way) so the if block was removed and replaced with a loop so that serial input can be handled when wifi manag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
    [Radio.h]
2023-09-27 Fix bug where LED reset was used incorrectly, finished testing
    [Radio.h]
2023-09-27 Not customizing setup page at this time. The update function may become useful for programming later on, the other buttons can be explained in a video
2023-10-08 Completely rewrote the LEDStatus object, simplifying it. It is not implemented
2023-10-08 LEDStatus config is now passed at init, not instantiation.
2023-10-08 Changed to work with new LEDStatus object
2023-10-15 Refactored LED Status to have codes for when the LEDs are off, instead of a single code (-1)
2024-01-17 Added freecad files and stl files for knobs
    [channel-knob.FCStd, channel-v1.stl, v1.stl]
2024-01-18 If the request to the settings server throws an error, then don't update the local config.
    [Radio.h]
2024-01-21 Removed unused screw holes, corrected shape of pads
    [v1-USMX.kicad_pcb]
2024-01-21 Moved serial pins to an area that offers easier access with a clamp fixture, even after installation
    [v1-USMX.kicad_pcb]
2024-01-21 Changed pcb version number
    [v1-USMX.kicad_pcb]
2024-01-23 Added fab files for v1.0-USMX-B
    [v1-USMX-B_Cu.gbl, v1-USMX-B_Mask.gbs, v1-USMX-B_Paste.gbp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]
2024-02-24 worked out some bugs with the helm chart, get it working in prod
    [values.yaml]
2024-03-22 Fixed syntax, misc, compiled firmware v1.0.0-beta.4
    [Radio.h, qr_code_webcam.py]
2024-03-22 Updated version number, fixed bug where timeout was in s, not ms
    [Radio.h, firmware.ino]
2024-09-10 Added a timeout that restarts the esp if it is in WiFi Setup mode for more than 15 minutes.
    This helps restart after a power failure, where the esp boots before a router and the esp would otherwise be stuck in a loop waiting to be configured.
    [Radio.h, firmware.ino]
2025-08-12 Added stl files
    [Housing.stl, Speakers.stl]
2025-08-12 Improves serial port communication and handling
    Refines serial port communication by increasing sleep durations
    after writing data and while reading configuration,
    enhancing reliability.
    Adds serial port auto-detection with an exclusion list to
    prevent connection to unwanted ports.
    Improves output by printing the port being used.
    [serial_programmer.py]
2025-08-12 Adds QR code webcam scanner
    Implements a QR code scanner using the webcam.
    It initializes the camera, captures frames, detects QR codes,
    and extracts a UUID from the decoded data. Includes error
    handling and camera auto-detection for improved reliability
    on Linux systems.
    [qr_code_webcam.py]
2025-11-07 Updates default target device path
    Updates the default target device path to '/dev/ttyACM0'.
    This resolves an issue where the programmer was not correctly
    targeting the serial device, likely due to a typo in the path.
    [serial_programmer.py]
